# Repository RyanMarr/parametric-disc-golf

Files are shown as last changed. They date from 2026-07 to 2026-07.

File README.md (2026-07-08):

# Parametric Disc Golf Disc Generator

Design your own disc golf discs. This repo is a parametric OpenSCAD model of a disc golf disc, plus preset numbers for 28 famous
PDGA-approved molds and a web-based designer. Punch in the four official PDGA
measurements for any approved disc, tune a handful of shape sliders to match its
silhouette, and print your own prototypes.

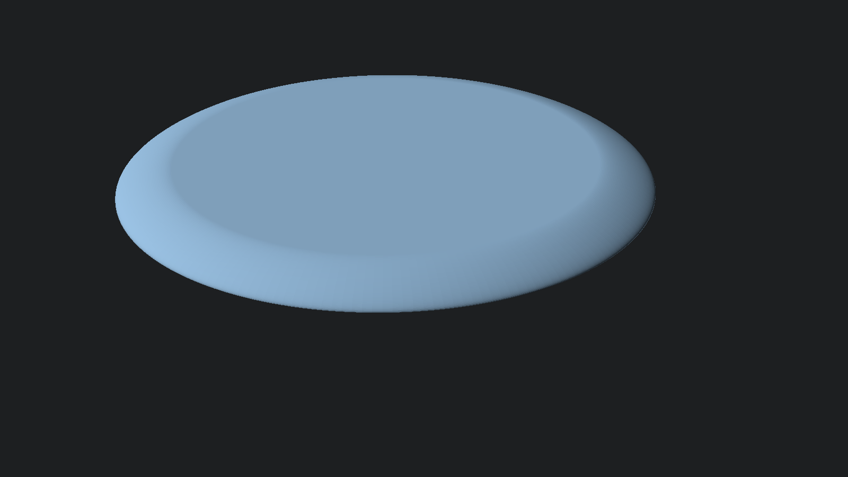
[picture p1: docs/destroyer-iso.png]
Destroyer-style distance driver rendered from disc.scad


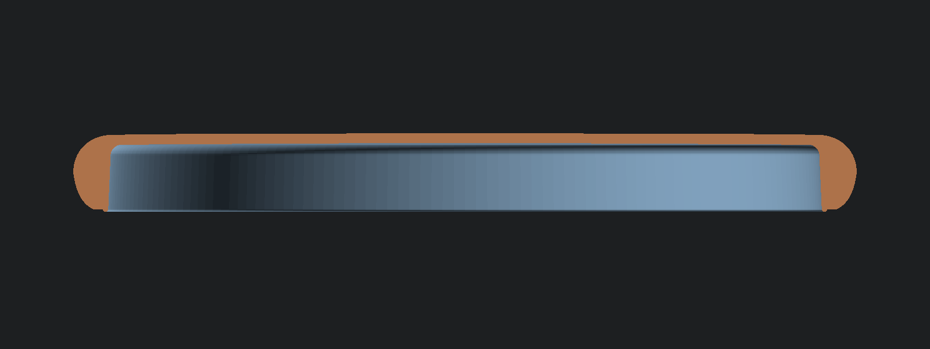
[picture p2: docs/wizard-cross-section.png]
Wizard-style putter cross-section (Customizer preset)


## Files

| File | What it is |
|---|---|
| `disc.scad` | The parametric model. Open in OpenSCAD, tweak via **Window → Customizer**, export STL. |
| `disc.json` | Customizer preset sets for all 28 famous molds — loads automatically next to `disc.scad` (pick a preset from the Customizer dropdown). |
| `designer.html` | Interactive designer: live cross-section preview, weight estimate, PDGA legality checks, shareable URLs. **[Use it online](https://ryanmarr.github.io/parametric-disc-golf/designer.html)** or just double-click the file (no server needed). |

## Quick start

**OpenSCAD route:** open `disc.scad`, open the Customizer (Window → Customizer),
pick e.g. *Innova Destroyer* from the preset dropdown, press F6, export STL.
The console `echo` prints the estimated solid volume/weight and PDGA legality notes.

**Web route:** open `designer.html`, pick a preset, drag sliders. The estimated
weight and legality checks update live. When you like it:

- **Copy shareable URL** — the full design is encoded in the URL; bookmark it or send it to yourself to return to the exact design later.
- **Copy OpenSCAD values** — paste over the variables at the top of `disc.scad`.
- **Download Customizer preset (.json)** — import in OpenSCAD's Customizer ("+" button).

The web preview and the SCAD model share the identical Bezier profile and
Pappus-theorem weight math, so the numbers match exactly.

## Parameters

The four **PDGA measurements** come straight off any disc's certification page at
[pdga.com → Technical Standards → Approved Discs](https://www.pdga.com/technical-standards/equipment-certification/discs)
(PDGA lists them in cm; the model uses mm):

- `diameter` — outer diameter ("Diameter")
- `height` — resting plane to top center ("Height")
- `rim_depth` — rim bottom to flight-plate underside ("Rim Depth")
- `rim_width` — outer edge to inner rim wall ("Rim Thickness")

**Shape character** sliders control what PDGA numbers can't capture:

- `flat_top` — **print-ready mode**: the entire top becomes a perfect plane (dome and shoulder roll are ignored; the dome region is filled solid) and the model is exported **top-down**, so the STL drops into Bambu Studio / any slicer with no rotation and **no supports**. Discs print upside down, and a domed top only touches the build plate at a point — this mode trades the dome for a clean support-free print.
- `flat_top_chamfer` (30–60°, flat-top only) — the round shoulder naturally leaves the flat plane horizontally, which is a 90° overhang printed top-down (the first layers droop right where your thumb sits). This clamps the shoulder under a straight chamfer at the given angle from horizontal (default 45° = safe on any printer) that blends back into the original curve where it's naturally steeper. Lower values keep more of the round shoulder but need a printer that handles shallow overhangs. The designer shows the resulting worst-case print overhang live and warns when a wide/low rim can't fully resolve (a small flat ring remains at the parting line).
- `dome` (0–1) — flat top → very domey. Note: actual dome *height* is `height − rim_depth − plate_thickness`, which falls out of the PDGA numbers; this slider shapes the curve.
- `shoulder_roll` (0–1) — 0 keeps a flat band on top of the rim (visible crease where the dome meets it); higher values roll the dome continuously over the shoulder toward the nose, like most real molds. No effect on flat-top discs.
- `nose_height` (0.05–0.9) — the **parting line**: where the widest point sits, as a fraction of height. The dominant stability driver — Paradox ≈ 0.15 (super flippy), drivers ≈ 0.3, putters ≈ 0.5, Tilt ≈ 0.8 (parting line at the top plate, hyzer-only).
- `nose_sharpness` (0–1) — blunt putter nose → sharp driver nose. Roughly the inverse of PDGA's "Rim Configuration" rating (putters 55–70 → ~0.1; drivers 26–30 → ~0.75).
- `wing_shape` (−1 to +1) — concave driver undercut → straight → convex putter wing.
- `bottom_land` — width of the flat band the disc rests on.
- `bead` — bead size in mm (0 = beadless). A circular lobe at the rim's bottom-inside corner, always tangent to the resting plane (the bead ring is what the disc rests on; with a bead the land floats above it). Micro bead ≈ 0.4, classic (Wizard/Judge) ≈ 0.8–1, big bead ≈ 1.5.
- `bead_angle` (0–90°) — the direction the bead protrudes: **0° = straight down** from the rim bottom at the wall line (how most beaded putters look — default), 45° ≈ the diagonal lobe in Innova's patent cross-section (US5531624 fig. 17), 90° = inward from the wall.
- `plate_thickness`, `inner_wall_draft` — flight plate and inner rim details.
- `wall_fillet` / `wall_fillet_height` — the blend where the inner rim wall meets the flight plate underside: `wall_fillet` is how far it spreads inward along the plate, `wall_fillet_height` how far it reaches down the wall. The fillet is tangent-matched to both surfaces (it follows the wall's draft angle and the underside's launch angle), so it flows instead of forcing a right angle.
- `label_text` — optional text engraved into the **underside** of the flight plate, centered (mirrored so it reads correctly when you flip the disc over; `label_size`/`label_depth` to taste).

## Famous mold presets (PDGA-verified, July 2026)

Dimensions scraped from each mold's official PDGA certification page. Flight
numbers are manufacturer-published. All lengths in mm, max weight in g.

| Disc | Flight | Ø | Height | Rim depth | Rim width | Max wt |
|---|---|---|---|---|---|---|
| **Putters & approach** |
| Innova Aviar P&A | 2/3/0/1 | 212 | 20 | 15 | 9 | 176.0 |
| Dynamic Discs Judge | 2/4/0/1 | 212 | 20 | 15 | 11 | 176.0 |
| Discmania P2 | 2/3/0/1 | 212 | 21 | 15 | 10 | 176.0 |
| Discraft Luna | 3/3/0/2 | 211 | 20 | 14 | 11 | 175.1 |
| Discraft Zone | 4/3/0/3 | 211 | 20 | 13 | 12 | 175.1 |
| Axiom Envy | 3/3/−1/2 | 210 | 18 | 14 | 11 | 174.3 |
| Gateway Wizard | 2/3/0/2 | 210 | 21 | 18 | 10 | 174.3 |
| **Midranges** |
| Discraft Buzzz | 5/4/−1/1 | 217 | 19 | 13 | 12 | 180.1 |
| Innova Roc3 | 5/4/0/3 | 218 | 20 | 13 | 14 | 180.9 |
| Innova Mako3 | 5/5/0/0 | 217 | 19 | 14 | 14 | 180.1 |
| Discmania MD3 | 5/5/0/2 | 218 | 19 | 13 | 14 | 180.9 |
| Axiom Hex | 5/5/−1/1 | 214 | 16 | 13 | 14 | 177.6 |
| DD EMAC Truth | 5/5/0/2 | 217 | 18 | 12 | 15 | 180.1 |
| Axiom Paradox | 5/4/−4/0 | 215 | 18 | 13 | 13 | 178.5 |
| **Fairway drivers** |
| Innova Teebird | 7/5/0/2 | 212 | 15 | 11 | 17 | 176.0 |
| Innova Leopard | 6/5/−2/1 | 212 | 16 | 11 | 16 | 176.0 |
| Innova Eagle | 7/4/−1/3 | 212 | 16 | 12 | 17 | 176.0 |
| Latitude 64 River | 7/7/−1/1 | 215 | 19 | 12 | 18 | 178.5 |
| Discraft Undertaker | 9/5/−1/2 | 211 | 18 | 11 | 19 | 175.1 |
| Discmania FD | 7/6/−1/1 | 212 | 18 | 11 | 18 | 176.0 |
| Innova Roadrunner | 9/5/−4/1 | 211 | 14 | 12 | 18 | 175.1 |
| Discmania Tilt | 9/1/1/6 | 211 | 16 | 12 | 20 | 175.1 |
| **Distance drivers** |
| Innova Destroyer | 12/5/−1/3 | 211 | 14 | 12 | 22 | 175.1 |
| Innova Wraith | 11/5/−1/3 | 211 | 14 | 12 | 21 | 175.1 |
| Discraft Zeus | 12/5/−1/3 | 211 | 16 | 12 | 23 | 175.1 |
| Innova Shryke | 13/6/−2/2 | 211 | 17 | 12 | 23 | 175.1 |
| Discmania DD3 | 12/5/−1/3 | 210 | 18 | 12 | 24 | 174.3 |
| Discraft Nuke | 13/5/−1/3 | 212 | 16 | 12 | 25 | 176.0 |

## Estimated flight numbers

The designer (and the `echo` in disc.scad) estimates speed / glide / turn / fade
from the geometry as you design. The models are least-squares fits on this
repo's 28 PDGA-verified presets, with extreme discs (Tilt +1/6, Paradox −4/0,
Roadrunner −4) weighted more heavily so the stability scale spans the real
range; cross-validated leave-one-out (typical error ±0.6–0.8 per number —
comparable to published attempts on 900+ discs):

- **Speed** ← rim width. The dominant driver everywhere: r = 0.96 on a
  112-disc Innova dataset ([engenmt/Disc-Golf](https://github.com/engenmt/Disc-Golf)),
  whose fit (speed ≈ 7.11 × rim-width-cm − 4.77) matches ours. Roughly +1 speed per +1.4 mm of rim.
- **Glide** ← dome height (camber → lift), rim width, and (negatively) rim-depth-to-diameter ratio.
- **Turn & fade** ← nose height (plus dome, and wing shape for turn). Nose
  height **is** the parting-line height — the community's strongest stability
  predictor (higher PLH = more overstable): [Flight Factory](https://flightfactorydiscs.com/blogs/flightfactoryblog/how-parting-line-height-and-dome-measurements-help-predict-flight),
  [Mint Discs](https://mintdiscs.com/blogs/news/understanding-your-disc-volume-1-parting-line-height).
  The Tilt (parting line at the top plate) and Paradox (parting line at the
  bottom) anchor the two ends of the scale.
  Flat tops add fade; domey tops add turn ([DG Puttheads](https://www.dgputtheads.com/how-dome-height-changes-flight-stability)).

Caveats worth knowing: manufacturer flight numbers are marketing estimates,
not measurements, and are inconsistent across brands; glide is the most
inflated number ([straslerj's analysis](https://github.com/straslerj/disc-golf-flight-numbers))
and the model can't see outliers like the Tilt's glide-1 brick flight; the
Roadrunner's −4 turn still reads as ≈ −2.5; and printed weight, plastic
stiffness, and your arm speed all shift real flight.
Physics background: Hummel's [Frisbee flight simulation thesis](https://morleyfielddgc.wordpress.com/wp-content/uploads/2009/04/hummelthesis.pdf)
and Potts & Crowther's wind-tunnel work.

## PDGA legality (what the checks enforce)

From the current [PDGA Technical Standards](https://www.pdga.com/technical-standards)
(May 2026 revision):

- **Weight** ≤ 8.3 g per cm of diameter (so a 21.1 cm disc caps at 175.1 g), absolute max 200 g
- **Diameter** 21.0–30.0 cm
- **Rim depth** 5–12 % of diameter
- **Rim width** ≤ 2.6 cm; **inside rim diameter** ≥ 15.8 cm
- **Flight plate** ≤ 0.5 cm thick; underside ≥ 0.3 cm above the rim-bottom plane
- **Leading edge** must pass a 1.6 mm radius gauge (no razor noses)
- **Rim configuration** rating ≥ 26; flexibility ≤ 12.25 kg; rim bottom must sit flush; no holes in the flight plate

Homemade discs aren't tournament-legal anyway (discs must be produced by a
registered manufacturer), but staying inside these numbers keeps your prototypes
flying like the real thing.

## Printing tips

- **Material:** TPU (~95A) is the community favorite — durable and flexible like premium plastic. PETG works for stiff, overstable prototypes; PLA is easy but shatters on trees.
- **Weight:** the estimate is solid volume × density × `print_factor`. The 0.94 default is calibrated from a real 100 %-infill PLA print (167 g measured vs 178.4 g theoretical — even "solid" FDM prints run a few percent light from micro-voids and slight underextrusion). Re-calibrate for your printer by weighing one print and setting `print_factor` = measured ÷ theoretical. Tune slicer infill/walls down to hit lower targets.
- **Orientation:** discs print upside down (top on the plate). Turn on `flat_top` for a support-free print — it makes the top perfectly planar and exports the STL already flipped, ready to slice. A domed top printed upside down touches the plate at a single point and needs supports, which rarely come out well.
- **First layer:** the bottom land is the resting surface — a clean first layer matters. A slight negative `wing_shape` reduces elephant-foot impact on flight.
- Export at `smoothness = 200+` and `curve_steps = 48+` for production STLs.

## Data sources

- PDGA approved-disc database: https://www.pdga.com/technical-standards/equipment-certification/discs (per-disc pages, e.g. [Destroyer](https://www.pdga.com/technical-standards/equipment-certification/discs/destroyer), [Buzzz](https://www.pdga.com/technical-standards/equipment-certification/discs/buzzz), [Judge](https://www.pdga.com/technical-standards/equipment-certification/discs/judge))
- PDGA Technical Standards: https://www.pdga.com/technical-standards ("Revised May 7, 2026" edition)
- Flight numbers: manufacturer catalogs (Innova, Discraft, Discmania, Dynamic Discs, Latitude 64, Axiom/MVP, Gateway)

## License

MIT — see [LICENSE](LICENSE). Disc mold names belong to their manufacturers; the
measurements are public data from the PDGA certification database. This project
is for personal prototyping and is not affiliated with the PDGA or any manufacturer.

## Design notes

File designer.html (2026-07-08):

# 🥏 Disc Golf Disc Designer

Companion to disc.scad — same curves, same weight math. Tweak, copy the numbers (or the URL), print, throw.

Preset (famous PDGA molds)

Show preset outline as ghost while tweaking

PDGA measurements (mm)

Shape character

Flat top (print-ready) — perfectly flat top, STL exported top-down: drops into the slicer with no rotation and no supports. Dome & shoulder roll ignored.

Material (solid print)

Densityg/cm³ — match your filament spec sheet

Print factormeasured ÷ theoretical — even "100% infill" prints run a few % light

Weight = solid volume × density × print factor. The 0.94 default was calibrated against a real 100%-infill PLA print (167 g measured vs 178.4 g theoretical). Set it to 1 for the pure theoretical weight.

Est. weight (printed)

–

PDGA max weight

–

Solid volume

–

Dome height

–

Inside rim Ø

–

Rim depth / Ø

–

### Estimated flight numbers — from geometry; typical error ±0.6–0.9 per number

Speed tracks rim width; glide tracks dome height; turn & fade lean on nose height (a parting-line-height proxy) and dome. Fit to the 28 presets — treat as a starting point, not gospel.

### PDGA legality (Technical Standards, 2026 revision)

📋 Copy shareable URL Copy OpenSCAD values Download Customizer preset (.json)

Paste these over the top of disc.scad, or download the .json and load it via OpenSCAD → Window → Customizer → “+” (import preset). The estimated weight here uses the identical profile polygon and Pappus’s theorem, so it matches the echo in OpenSCAD.

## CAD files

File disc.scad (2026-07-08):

// ============================================================
//  Parametric Disc Golf Disc  —  disc.scad
// ============================================================
//  Punch in the four official PDGA measurements (diameter,
//  height, rim depth, rim width) for any approved mold, then
//  tune the shape-character sliders to match its silhouette.
//
//  Preset numbers for 28 famous molds live in disc.json
//  (OpenSCAD Customizer parameter sets: Window > Customizer,
//  then pick a preset from the dropdown) and in README.md.
//
//  A companion web designer (designer.html) previews the
//  cross-section + estimated weight and emits these numbers.
//
//  Geometry: the half cross-section is built from four cubic
//  Bezier curves (top, wing underside, bead/inner wall, flight
//  plate underside) and revolved with rotate_extrude. The same
//  math is mirrored in designer.html, so what you preview there
//  is what prints here.
// ============================================================

/* [Key PDGA Measurements (mm)] */
// Outer diameter (PDGA "Diameter", cm x 10)
diameter = 211.0; // [200:0.5:225]
// Overall height at center (PDGA "Height")
height = 14.0; // [10:0.1:25]
// Bottom of rim to underside of flight plate at the rim (PDGA "Rim Depth")
rim_depth = 12.0; // [8:0.1:18]
// Outer edge to inside rim wall (PDGA "Rim Thickness")
rim_width = 22.0; // [8:0.1:26]

/* [Shape Character] */
// Print-ready flat top: the entire top becomes a perfect plane (dome and shoulder_roll ignored) and the model is oriented top-down, ready to print without supports
flat_top = false;
// Flat-top only: minimum shoulder steepness in degrees from horizontal. The round shoulder is clamped to this chamfer so it prints cleanly top-down (overhang = 90 minus this). 45 is safe everywhere; drop toward 35 if your printer/cooling handles shallow overhangs and you want more of the round shoulder back
flat_top_chamfer = 45; // [30:1:60]
// 0 = flat top, 1 = very domey (ignored when flat_top is on)
dome = 0.45; // [0:0.01:1]
// Rolls the dome smoothly over the shoulder: 0 = flat shoulder band, 1 = continuous rollover into the nose (no effect on flat tops)
shoulder_roll = 0.35; // [0:0.01:1]
// Parting line: height of the widest point as a fraction of disc height (Paradox ~0.15, most discs 0.3-0.5, Tilt ~0.8)
nose_height = 0.35; // [0.05:0.01:0.9]
// 0 = blunt rounded nose (putter), 1 = sharp aerodynamic nose (driver)
nose_sharpness = 0.7; // [0:0.01:1]
// Underside of the wing: -1 = concave undercut (driver), 0 = straight, 1 = convex rounded (putter)
wing_shape = -0.25; // [-1:0.01:1]
// Width of the flat resting land on the rim bottom
bottom_land = 3.0; // [1:0.1:8]
// Bead radius on inner-bottom of rim (0 = beadless)
bead = 0.0; // [0:0.1:2.5]
// Direction the bead protrudes: 0 = straight down from the rim bottom (typical), 90 = inward from the wall
bead_angle = 0; // [0:1:90]
// Flight plate thickness at center
plate_thickness = 2.0; // [1.2:0.05:4]
// Inner rim wall lean, degrees outward at the bottom
inner_wall_draft = 2.0; // [0:0.5:10]
// Fillet where inner wall meets flight plate: spread along the plate underside (mm)
wall_fillet = 3.0; // [0:0.1:6]
// How far the same fillet reaches down the inner wall (mm)
wall_fillet_height = 3.0; // [0:0.1:8]

/* [Weight Estimate] */
// g/cm^3 — TPU 1.21, PETG 1.27, PLA 1.24, ABS 1.04, PP 0.90
density = 1.21; // [0.8:0.01:1.5]
// Printed weight / theoretical solid. Even "100% infill" prints run a few percent light (micro-voids, slight underextrusion); calibrated from a real PLA test print: 167 g measured vs 178.4 g theoretical = 0.936
print_factor = 0.94; // [0.8:0.01:1]

/* [Output] */
// Render only half the disc to inspect the cross-section
cross_section = false;
// Optional text engraved into the underside of the flight plate, centered (reads correctly looking at the disc bottom)
label_text = "";
// Engraved text size
label_size = 12; // [6:1:24]
// Engraving depth
label_depth = 0.4; // [0.2:0.05:1]
// Rotational smoothness (segments)
smoothness = 200; // [60:4:360]
// Points per Bezier curve
curve_steps = 48; // [12:4:96]

/* [Hidden] */
$fs = 0.4;
$fa = 2;

// ---------------- Bezier helpers ----------------
function _lerp(a, b, t) = a + (b - a) * t;
function _lerp2(p, q, t) = [_lerp(p[0], q[0], t), _lerp(p[1], q[1], t)];
function bez3(p0, p1, p2, p3, t) =
    let (u = 1 - t)
    [ u*u*u*p0[0] + 3*u*u*t*p1[0] + 3*u*t*t*p2[0] + t*t*t*p3[0],
      u*u*u*p0[1] + 3*u*u*t*p1[1] + 3*u*t*t*p2[1] + t*t*t*p3[1] ];
// n+1 points including both endpoints
function bezpts(p0, p1, p2, p3, n) = [for (i = [0:n]) bez3(p0, p1, p2, p3, i/n)];
// same but skipping the first point (avoids duplicates when chaining)
function bezpts_tail(p0, p1, p2, p3, n) = [for (i = [1:n]) bez3(p0, p1, p2, p3, i/n)];
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

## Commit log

2026-07-02 Parametric disc golf disc: OpenSCAD model, 27 PDGA-verified presets, web designer
    - disc.scad: Bezier-profile parametric disc (PDGA measurements + shape
    sliders), Pappus weight estimate, PDGA legality checks, underside
    label engraving, cross-section view
    - disc.json: OpenSCAD Customizer preset sets for 27 famous molds,
    dimensions verified against the PDGA certification database
    - designer.html: zero-dependency web designer with live cross-section,
    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
    [disc.scad]
2026-07-02 Fix flight plate thinning near the shoulder
    The wall fillet's control point sat above the wall top, so the plate
    underside bulged upward near the rim: plate thickness dropped to
    1.78mm (nominal 2.0) on the Destroyer preset and 1.86mm (nominal 3.0)
    on the Judge just inside the shoulder.
    The underside now lands on the shoulder at z_S - plate_thickness,
    mirroring the top curve, and wall_fillet is a true corner fillet that
    curves down into the inner wall (adding material to the cavity corner).
    Plate thickness verified constant at nominal across the whole plate;
    SCAD and JS volumes still match exactly (154.7 cm^3 default).
    Claude-Session: h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
    [disc.scad]
2026-07-02 Add shoulder_roll: blend the dome over the shoulder
    At the shoulder the plate-top curve flattened into a horizontal rim
    band; the junction was tangent-continuous but the curvature jump read
    as a subtle dip/crease on domed discs. shoulder_roll (0-1, default
    0.35) tilts the shared tangent at the shoulder so the dome rolls
    continuously over the rim toward the nose. The tilt fades to zero as
    dome height approaches zero, so flat-top discs are unchanged. The six
    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
    [disc.scad]
2026-07-02 Reorient the bead: down-and-inward corner lobe per Innova patent
    The bead was a semicircle centered on the inner wall line at z=bead,
    protruding purely inward like a mid-wall bump (obvious at large
    values). Per Innova patent US5531624 fig.17 and community sources, a
    real bead is a widening of the rim's bottom-inside corner: a rounded
    lobe at the foot of the inner wall protruding diagonally down-and-in,
    underside tangent to the resting plane (it is the contact ring), top
    swelling smoothly back into the wall.
    Rebuilt as two beziers: grounded foot -> low apex (inward bead-mm at
    z=0.8*bead) -> ogee into the wall at z=2.4*bead. Fillet clearance
    guard updated. Data corrections from the same resea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
    [disc.scad]
2026-07-02 Bead hangs below the rim bottom, not just inward of the wall
    The lobe was grounded flush with the bottom land, so its only visible
    protrusion was inward. Per the patent cross-section the bead bulges
    past BOTH corner lines: with a bead the land now floats 0.4*bead above
    the resting plane, a shallow cove drops from the land to the grounded
    bead foot (z=0 stays the resting plane - the bead ring is the contact
    surface), then the lobe rounds up-inward to its low apex and swells
    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
    [disc.scad]
2026-07-02 Add bead_angle: parameterize the bead protrusion direction
    Reference photos of real beaded putters show the bead ring jutting
    essentially straight down from the rim bottom at the wall line, not
    diagonally inward. The bead is now a circular lobe (radius 0.85*bead)
    always tangent to the resting plane, with bead_angle setting where it
    points: 0 = straight down (default, land floats 0.8*bead above the
    contact ring, wall flows straight into the lobe), ~45 = the diagonal
    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
    [disc.scad]
2026-07-02 Regenerate README renders with corrected bead geometry
    The Wizard cross-section predated the bead reorientation (and the
    shoulder-roll and plate-thickness fixes); both preview images now
    reflect the current profile math.
    Claude-Session: https://claude.ai/code/session_012zvrqdRSwQHMtHrkk3oGyu
2026-07-02 Add live flight-number estimate (speed/glide/turn/fade)
    Least-squares models fit on the repo's 27 PDGA-verified presets,
    leave-one-out cross-validated (MAE: speed 0.56, glide 0.81, turn 0.57,
    fade 0.86 - comparable to published fits on 900+ discs). Feature
    choices follow the research consensus: speed <- rim width (r=0.96 on a
    112-disc Innova dataset, slope matches engenmt/Disc-Golf's published
    fit); glide <- dome height + rim width - rim-depth ratio; turn/fade <-
    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
    [disc.scad]
2026-07-02 Calibrate stability scale with real parting lines; add Axiom Paradox
    The turn/fade fits compressed the extremes (Tilt fade predicted 3 vs
    its real 6). Root cause was data, not sensitivity: nose_height IS the
    parting line, and the presets had generic values where the real discs
    are extreme. Per profile photos, the Tilt's parting line sits at the
    top plate (nh 0.4 -> 0.8) and the Roadrunner's is low (0.33 -> 0.28).
    Added the Axiom Paradox (PDGA-verified: 215/18/13/13mm, 5/4/-4/0,
    cert 21-71), the flippiest mid in production, with nh 0.15 anchoring
    the understable end. nose_height range extended to 0.05-0.9.
    Refit turn/fade on the 28 molds with extremes weighted 1+0.6*|value|,
    wing_shape added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
    [disc.scad]
2026-07-02 Designer UX: fillet height control, per-param reset, full-height layout
    - wall_fillet_height: the corner blend's reach down the inner wall is
    now independent of wall_fillet (its spread along the plate underside).
    Both default to 3 so existing designs are unchanged.
    - The fillet is now tangent-matched (G1) on both sides: it follows the
    wall's draft angle at its foot and the underside's launch angle (the
    shoulder-roll angle, mirroring the plate top) at its landing, and the
    plate underside leaves the corner at that same angle. Kills the
    forced right angle + shelf that appeared on domey/short-rim discs;
    plate thickness verified still nominal (River 2.20/2.20).
    - Per-parameter reset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
    [disc.scad]
2026-07-08 Add flat-top print mode and calibrated print-weight factor
    flat_top (SCAD bool + designer checkbox, URL key ft): the entire top
    becomes a perfect plane at z=height (dome and shoulder_roll ignored,
    dome region filled solid; underside keeps its rim_depth geometry) and
    the model is exported top-down - top plane verified sitting exactly on
    z=0 - so the STL drops into the slicer with no rotation and no
    supports. Discs print upside down; a domed top touches the plate at a
    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
    [disc.scad]
2026-07-08 disc.json: mold presets only — drop locally saved test preset
    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
2026-07-08 Add flat_top_chamfer: printable shoulder for flat-top mode
    In flat-top mode the shoulder leaves the plate horizontally - a 90 deg
    overhang printed top-down. Measured on a real flat-top putter export:
    first layer steps out ~1mm (79 deg) and the surface stays past 45 deg
    for the first ~2.5mm, drooping exactly where the thumb sits.
    flat_top_chamfer (30-60 deg, default 45) clamps the shoulder under a
    cone at that angle from the plate edge; the cone rejoins the original
    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
    [disc.scad]
2026-07-08 flat-top: curved shoulder instead of straight cone facet
    The cone clamp on a blunt round-shouldered putter replaces nearly the
    whole shoulder with a flat bevel (looks machined, feels wrong). Now the
    shoulder in flat-top mode is rebuilt as a smooth convex curve: it
    departs the plate at the chamfer angle and steepens monotonically to
    the vertical nose, so every point is printable but the profile stays
    disc-like. The cone clamp remains as a safety net only (a convex curve
    falls below its departure tangent, so it rarely engages).
    Verified on the FlippyPutter geometry: worst overhang exactly 90-fc
    (45 at default, 40 at fc=50); SCAD/JS parity exact (135.6 cm^3).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
    [disc.scad]
